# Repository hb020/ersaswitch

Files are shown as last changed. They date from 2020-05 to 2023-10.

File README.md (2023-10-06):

# ersaswitch

This project is about an external switch to an Ersa i-CON controller.
It allows switching between tools, without voiding Ersa warranty (at least, nothing from Ersa is opened and no wires are cut), and without occupying more desk space.

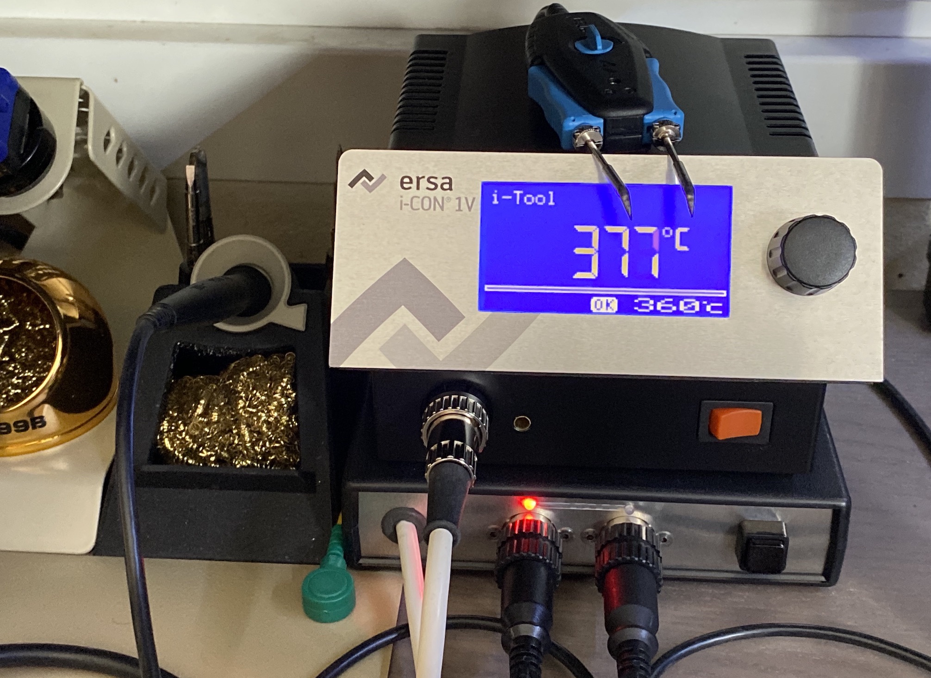
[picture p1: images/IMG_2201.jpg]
how it looks like


Inspired by https://www.eevblog.com/forum/reviews/ersa-i-con2v-(port-switch-hack)/

But I have an i-con 1V.

The switch has 3 states: left, right and a timed inbetween "no tool". The latter is mandatory between left/right tools for about 2 secs for the controller to not freak out. The switch is fully isolated, and via monitoring of the signals, switches itself on and off automatically in sync with the controller.

There is stuff inside this git repo about implementing communication with the tools to show "too hot to touch" temperatures of the disconnected tool, but that was put on hold, as I wanted to try out the Attiny 214. That guy would probably be too small for a full comms stack and it would require some more components and a lot more time.

Does the switch work well? Yes, and it is a joy too, since the heat up time of the tools is so short. Really easy to use. One big pushbutton. I designed it so that the relay click pattern gives audible hints too, so in short time you don't even have to look anymore as for what tool is active. You just grab it.

Is it economically viable? Probably not for a one-off, as the BOM gets close to 100 EUR if you have to buy it all (meaning: case and so) in small qty locally from Europe or the US. Just get the i-con 2V if you really use multiple tools regularly. But on the other hand you could use this to extend the port range of a 2V to 3 tools or more if you want (while keeping your warranty).

This should be easy to extend to 3 or more tools though. Just keep in mind that not all Ersa tools use only 5 wires. I have the i-tool and the Chip Tool Vario, and they only have 2 for power, 2 for logic, and 1 for earth. Some tools have more lines. If you have a tool with more lines, you'll have to change the relays.

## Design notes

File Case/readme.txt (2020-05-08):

PCB cutout: generated by flatcam 8.99.. beta.
frontcutouts: QCad to bCNC, tweaked manually (and moved some)

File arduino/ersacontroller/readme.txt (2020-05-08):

How to program the Attiny 214:

You need an Arduino Nano or the like, programmed as jtag2updi.

Use the Arduino IDE for dev and programming. 
It is not my preferred environment, but it was the easiest way to get started with the Attiny 214 through MegaTinyCore.

Inside Arduino IDE:

Board: ATtiny1614/...../214/...
Chip: 214
Port: /dev/cu.usbserial-10
Programmer: jtag2updi (MegaTinyCore)

Arduino IDE digitalRead/Write pin naming:
0 = PA4 (chip pin 2)
1 = PA5 (chip pin 3)
2 = PA6 (chip pin 4)
3 = PA7 (chip pin 5)
4 = PB3 (chip pin 6)
5 = PB2 (chip pin 7)
6 = PB1 (chip pin 8)
7 = PB0 (chip pin 9)
8 = PA1 (chip pin 11)
9 = PA2 (chip pin 12)
10 = PA3 (chip pin 13)

Investigate board:

> wget https://raw.githubusercontent.com/ElTangas/jtag2updi/master/avrdude.conf
> avrdude -c jtag2updi -P /dev/tty.usbserial-10 -p t214 -v -C avrdude.conf

avrdude: Version 6.3, compiled on Oct 11 2019 at 01:39:52
         Copyright (c) 2000-2005 Brian Dean, http://www.bdmicro.com/
         Copyright (c) 2007-2014 Joerg Wunsch

         System wide configuration file is "avrdude.conf"
         User configuration file is "/Users/hboot/.avrduderc"
         User configuration file does not exist or is not a regular file, skipping

         Using Port                    : /dev/tty.usbserial-10
         Using Programmer              : jtag2updi
JTAG ICE mkII sign-on message:
Communications protocol version: 1
M_MCU:
  boot-loader FW version:        1
  firmware version:              6.00
  hardware version:              1
S_MCU:
  boot-loader FW version:        1
  firmware version:              6.00
  hardware version:              1
Serial number:                   00:00:00:00:00:00
Device ID:                       JTAGICE mkII
         AVR Part                      : ATtiny214
         Chip Erase delay              : 0 us
         PAGEL                         : P00
         BS2                           : P00
         RESET disposition             : dedicated
         RETRY pulse                   : SCK
         serial program mode           : yes
         parallel program mode         : yes
         Timeout                       : 0
         StabDelay                     : 0
         CmdexeDelay                   : 0
         SyncLoops                     : 0
         ByteDelay                     : 0
         PollIndex                     : 0
         PollValue                     : 0x00
         Memory Detail                 :

                                  Block Poll               Page                       Polled
           Memory Type Mode Delay Size  Indx Paged  Size   Size #Pages MinW  MaxW   ReadBack
           ----------- ---- ----- ----- ---- ------ ------ ---- ------ ----- ----- ---------
           signature      0     0     0    0 no          3    0      0     0     0 0x00 0x00
           prodsig        0     0     0    0 no         61   61      0     0     0 0x00 0x00
           fuses          0     0     0    0 no          9    0      0     0     0 0x00 0x00
           fuse0          0     0     0    0 no          1    0      0     0     0 0x00 0x00
           fuse1          0     0     0    0 no          1    0      0     0     0 0x00 0x00
           fuse2          0     0     0    0 no          1    0      0     0     0 0x00 0x00
           fuse4          0     0     0    0 no          1    0      0     0     0 0x00 0x00
           fuse5          0     0     0    0 no          1    0      0     0     0 0x00 0x00
           fuse6          0     0     0    0 no          1    0      0     0     0 0x00 0x00
           fuse7          0     0     0    0 no          1    0      0     0     0 0x00 0x00
           fuse8          0     0     0    0 no          1    0      0     0     0 0x00 0x00
           lock           0     0     0    0 no          1    0      0     0     0 0x00 0x00
           data           0     0     0    0 no          0    0      0     0     0 0x00 0x00
           usersig        0     0     0    0 no         32   32      0     0     0 0x00 0x00
           flash          0     0     0    0 no       2048   64      0     0     0 0x00 0x00
           eeprom         0     0     0    0 no         64   32      0     0     0 0x00 0x00

         Programmer Type : JTAGMKII_PDI
         Description     : JTAGv2 to UPDI bridge
         M_MCU hardware version: 1
         M_MCU firmware version: 6.00
         S_MCU hardware version: 1
         S_MCU firmware version: 6.00
         Serial number:          00:00:00:00:00:00
         Vtarget         : 5.0 V

avrdude: AVR device initialized and ready to accept instructions

Reading | ################################################## | 100% 0.05s

avrdude: Device signature = 0x1e9120 (probably t214)

avrdude done.  Thank you.

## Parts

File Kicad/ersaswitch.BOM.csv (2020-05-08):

Ref | Value | Footprint
C1 | 100nF | Capacitor_SMD:C_1206_3216Metric_Pad1.42x1.75mm_HandSolder
C2 | 100nF | Capacitor_SMD:C_1206_3216Metric_Pad1.42x1.75mm_HandSolder
C3 | 470uF | Capacitor_THT:CP_Radial_D10.0mm_P5.00mm
C4 | 100nF | Capacitor_SMD:C_1206_3216Metric_Pad1.42x1.75mm_HandSolder
C5 | 100uF | Capacitor_THT:CP_Radial_D6.3mm_P2.50mm
C6 | 100uF | Capacitor_THT:CP_Radial_D6.3mm_P2.50mm
C7 | 100nF | Capacitor_SMD:C_1206_3216Metric_Pad1.42x1.75mm_HandSolder
C8 | 4u7F | Capacitor_THT:CP_Radial_D5.0mm_P2.00mm
C9 | 100nF | Capacitor_SMD:C_1206_3216Metric_Pad1.42x1.75mm_HandSolder
C10 | 100nF | Capacitor_SMD:C_1206_3216Metric_Pad1.42x1.75mm_HandSolder
C11 | 100nF | Capacitor_SMD:C_1206_3216Metric_Pad1.42x1.75mm_HandSolder
C12 | 100nF | Capacitor_SMD:C_1206_3216Metric_Pad1.42x1.75mm_HandSolder
D1 | 1N4001 | Diode_SMD:D_SOD-123
D2 | 1N4001 | Diode_SMD:D_SOD-123
D3 | 1N4148 | Diode_SMD:D_SOD-123
D4 | 1N4148 | Diode_SMD:D_SOD-123
D5 | LED2_Dual_CAC | LED_THT:LED_D3.0mm-3
D6 | LED1_Dual_CAC | LED_THT:LED_D3.0mm-3
H1 | MountingHole | MountingHole:MountingHole_3mm
H2 | MountingHole | MountingHole:MountingHole_3mm
H3 | MountingHole | MountingHole:MountingHole_3mm
H4 | MountingHole | MountingHole:MountingHole_3mm
H5 | MountingHole | MountingHole:MountingHole_3mm
H6 | MountingHole | MountingHole:MountingHole_3mm
H7 | MountingHole | MountingHole:MountingHole_3mm
H8 | MountingHole | MountingHole:MountingHole_3mm
J1 | Conn_01x03_Male | TerminalBlock_Phoenix:TerminalBlock_Phoenix_MKDS-1,5-3-5.08_1x03_P5.08mm_Horizontal
J2 | Conn_01x01_Female | Connector_PinSocket_2.54mm:PinSocket_1x01_P2.54mm_Vertical
J3 | Conn_01x01_Male | Connector_PinHeader_2.54mm:PinHeader_1x01_P2.54mm_Horizontal
J4 | Conn_01x02_Male | mylib:PinHeader_1x02_P2.54mm_Vertical_for_rivets
J5 | Conn_01x06_Male | mylib:PinHeader_1x06_P2.54mm_Vertical_for_rivets
J6 | Conn_01x03_Male | mylib:PinHeader_1x03_P2.54mm_Vertical_biggerpads
J7 | Barrel_Jack_Switch | Connector_BarrelJack:BarrelJack_CUI_PJ-102AH_Horizontal
J8 | Conn_01x02_Male | mylib:PinHeader_1x02_P2.54mm_Vertical_for_rivets
J9 | Conn_01x06_Male | mylib:PinHeader_1x06_P2.54mm_Vertical_for_rivets
J10 | Conn_01x03_Male | Connector_PinHeader_2.54mm:PinHeader_1x03_P2.54mm_Horizontal
J11 | Conn_01x03_Female | Connector_PinSocket_2.54mm:PinSocket_1x03_P2.54mm_Vertical
J12 | Conn_01x03_Male | TerminalBlock_Phoenix:TerminalBlock_Phoenix_MKDS-1,5-3-5.08_1x03_P5.08mm_Horizontal
J13 | Conn_01x04_Male | TerminalBlock_Phoenix:TerminalBlock_Phoenix_MKDS-1,5-4-5.08_1x04_P5.08mm_Horizontal
J14 | Conn_01x03_Male | TerminalBlock_Phoenix:TerminalBlock_Phoenix_MKDS-1,5-3_1x03_P5.00mm_Horizontal
J15 | Conn_01x03_Male | TerminalBlock_Phoenix:TerminalBlock_Phoenix_MKDS-1,5-3_1x03_P5.00mm_Horizontal
J16 | Conn_01x01_Male | Connector_PinHeader_2.54mm:PinHeader_1x01_P2.54mm_Horizontal
J17 | Conn_01x01_Male | Connector_PinHeader_2.54mm:PinHeader_1x01_P2.54mm_Horizontal
J18 | Conn_01x01_Female | Connector_PinSocket_2.54mm:PinSocket_1x01_P2.54mm_Vertical
J19 | Conn_01x01_Female | Connector_PinSocket_2.54mm:PinSocket_1x01_P2.54mm_Vertical
J20 | Conn_01x01_Female | Connector_PinSocket_2.54mm:PinSocket_1x01_P2.54mm_Vertical
J21 | Conn_01x01_Male | Connector_PinHeader_2.54mm:PinHeader_1x01_P2.54mm_Horizontal
J22 | Conn_01x01_Female | Connector_PinSocket_2.54mm:PinSocket_1x01_P2.54mm_Vertical
J23 | Conn_01x01_Male | Connector_PinHeader_2.54mm:PinHeader_1x01_P2.54mm_Horizontal
J24 | Conn_01x01_Female | Connector_PinSocket_2.54mm:PinSocket_1x01_P2.54mm_Vertical
J25 | Conn_01x01_Male | Connector_PinHeader_2.54mm:PinHeader_1x01_P2.54mm_Horizontal
K1 | FINDER-41.52 | Relay_THT:Relay_DPDT_Finder_40.52
K2 | FINDER-41.52 | Relay_THT:Relay_DPDT_Finder_40.52
L1 | 18uH | Inductor_SMD:L_Taiyo-Yuden_NR-50xx_HandSoldering
PS1 | B1205LS-1WR2 | mylib:Converter_DCDC_BxxxxLS-1WR2
Q1 | BC817 | Package_TO_SOT_SMD:SOT-23
Q2 | BC817 | Package_TO_SOT_SMD:SOT-23
Q3 | IRFR5305 | Package_TO_SOT_SMD:TO-252-2
R1 | 4k7 | Resistor_SMD:R_1206_3216Metric_Pad1.42x1.75mm_HandSolder
R2 | 4k7 | Resistor_SMD:R_1206_3216Metric_Pad1.42x1.75mm_HandSolder
R3 | 1k? | Resistor_SMD:R_1206_3216Metric_Pad1.42x1.75mm_HandSolder
R4 | 10k | Resistor_SMD:R_1206_3216Metric_Pad1.42x1.75mm_HandSolder
R5 | 1M | Resistor_SMD:R_1206_3216Metric_Pad1.42x1.75mm_HandSolder
R6 | 4k7 | Resistor_SMD:R_1206_3216Metric_Pad1.42x1.75mm_HandSolder
R7 | 1k | Resistor_SMD:R_1206_3216Metric_Pad1.42x1.75mm_HandSolder
R8 | 10k | Resistor_SMD:R_1206_3216Metric_Pad1.42x1.75mm_HandSolder
R9 | 4k7 | Resistor_SMD:R_1206_3216Metric_Pad1.42x1.75mm_HandSolder
R10 | 680 | Resistor_SMD:R_1206_3216Metric_Pad1.42x1.75mm_HandSolder
R11 | 470 | Resistor_SMD:R_1206_3216Metric_Pad1.42x1.75mm_HandSolder
R12 | 680 | Resistor_SMD:R_1206_3216Metric_Pad1.42x1.75mm_HandSolder
R13 | 470 | Resistor_SMD:R_1206_3216Metric_Pad1.42x1.75mm_HandSolder
R14 | 0R | Resistor_SMD:R_2010_5025Metric_Pad1.52x2.65mm_HandSolder
R15 | 0R | Resistor_SMD:R_2010_5025Metric_Pad1.52x2.65mm_HandSolder
R16 | 0R | Resistor_SMD:R_2010_5025Metric_Pad1.52x2.65mm_HandSolder
R17 | 0R | Resistor_SMD:R_2010_5025Metric_Pad1.52x2.65mm_HandSolder
SW1 | SW_Push (connection) | mylib:PinHeader_1x02_P2.54mm_Vertical_for_rivets
U1 | ATtiny214-SS | Package_SO:SOIC-14_3.9x8.7mm_P1.27mm
U2 | AMS1117-5.0 | Package_TO_SOT_SMD:SOT-223-3_TabPin2
U3 | 74VHC1G132 | Package_TO_SOT_SMD:SOT-23-5_HandSoldering
U4 | PC817 | Package_DIP:DIP-4_W7.62mm_LongPads
Ref | Value | qty
Case | Hammond 1598BBBK | 1
DIN plug | PREHKEYTEC 71430-080/0800 | 1
DIN socket | PREHKEYTEC 71206-080/0800 | 2
Support for relay | Finder 95.15.2SMA | 2
PCB feet | TR FASTENINGS TRLCBSBM-4-01A2-RT - PCB Support, Lock-In Support With Adhesive Base, Nylon 6.6, 6.4mm x 4.4mm | 2
PCB feet | TR FASTENINGS TRLCBSBM-3-01A2-RT - PCB Support, Lock-In Support With Adhesive Base, Nylon 6.6, 4.8mm x 4.4mm | 2
Pushbutton | Multicomp MCPS23B-2 - Pushbutton Switch, Standard, 12 mm, SPST, (On)-Off, Square Raised | 1
fasteners |  | various
cabling |  | various

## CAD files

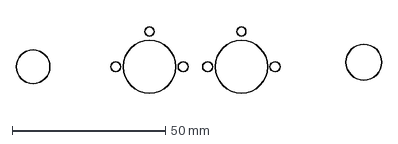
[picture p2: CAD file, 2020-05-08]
Case/frontcutouts.dxf
119.3 x 21.6 mm

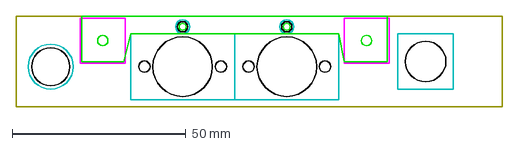
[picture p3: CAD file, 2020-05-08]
Case/front.dxf
140.0 x 26.0 mm

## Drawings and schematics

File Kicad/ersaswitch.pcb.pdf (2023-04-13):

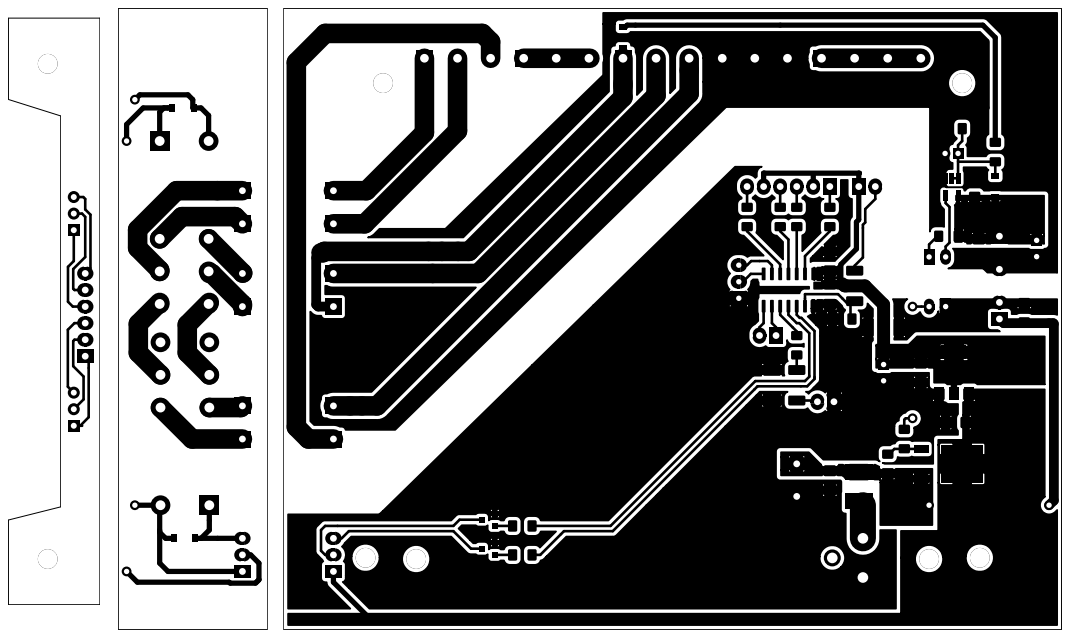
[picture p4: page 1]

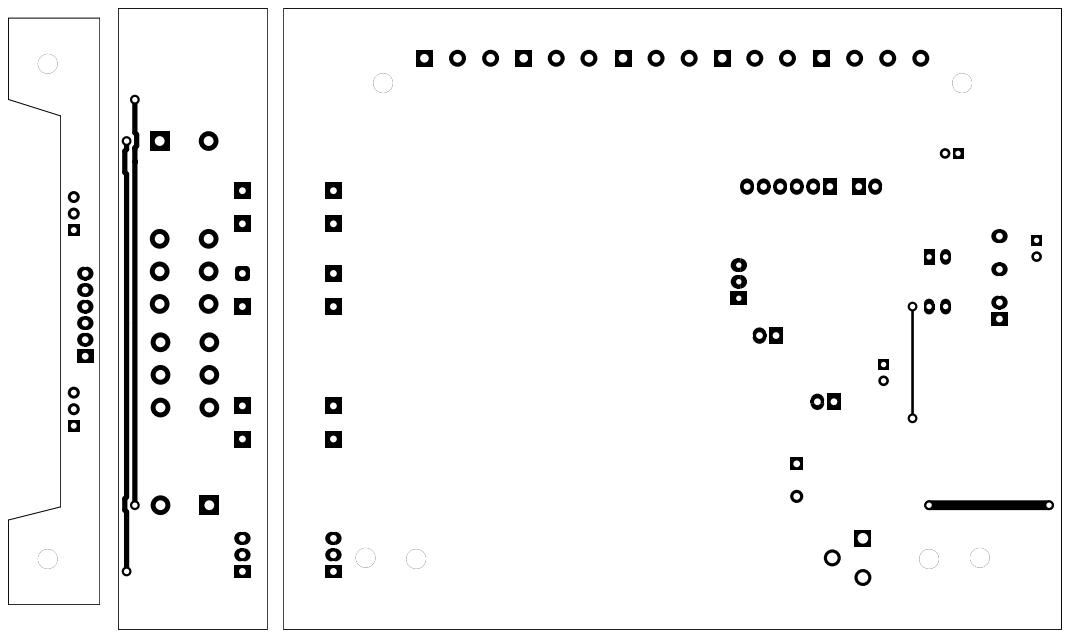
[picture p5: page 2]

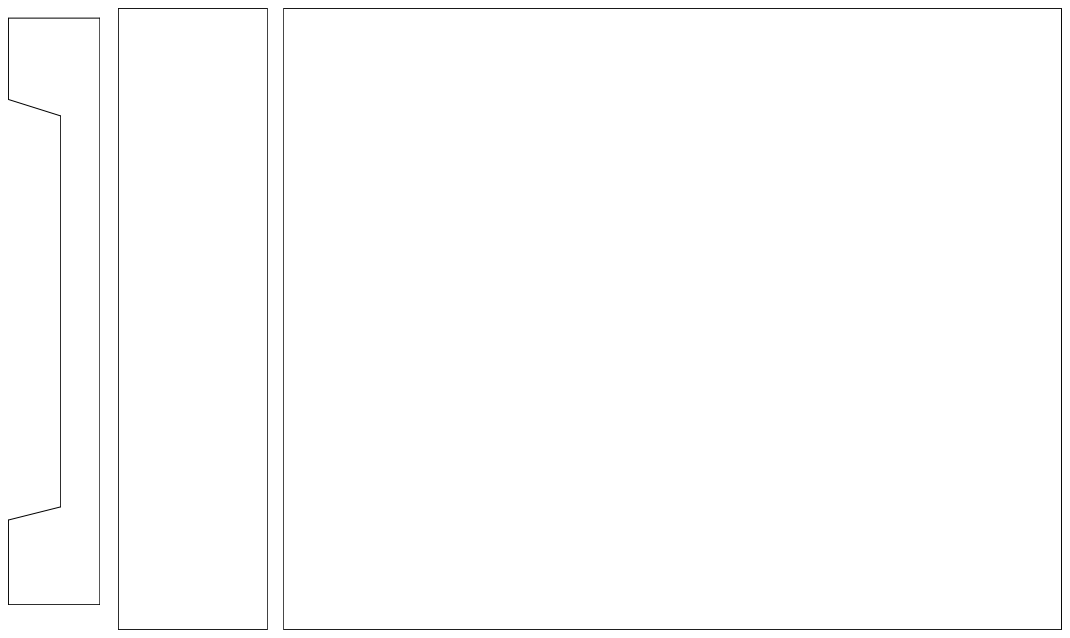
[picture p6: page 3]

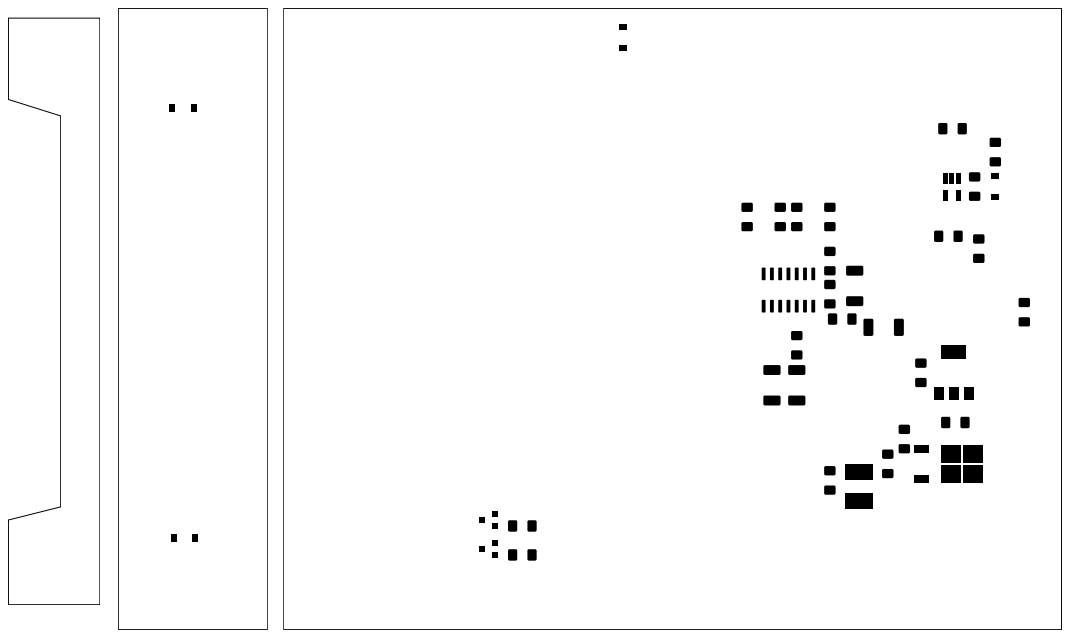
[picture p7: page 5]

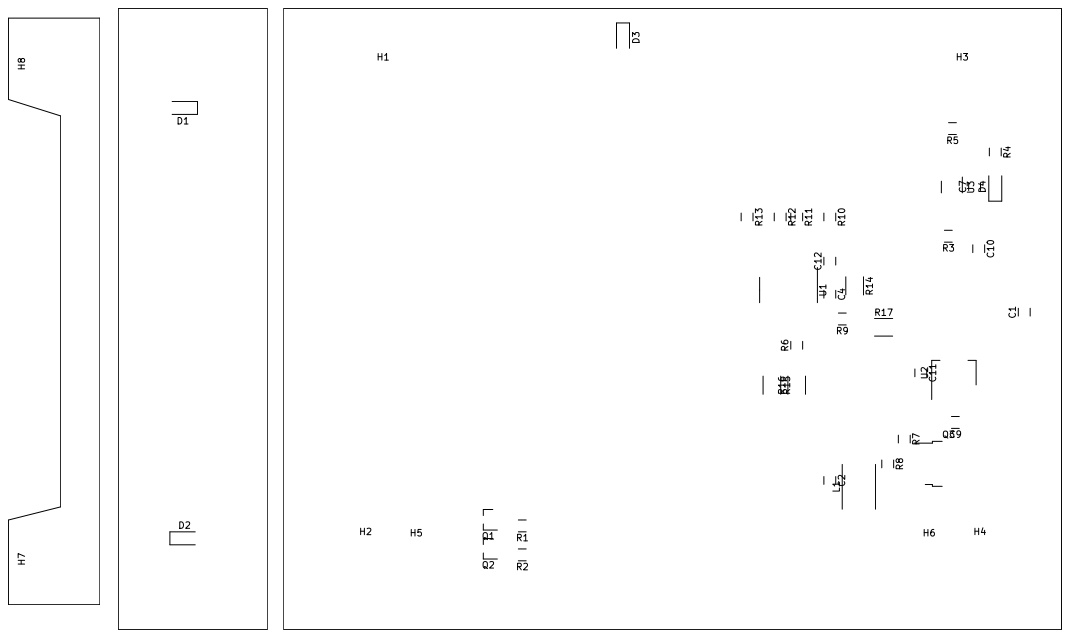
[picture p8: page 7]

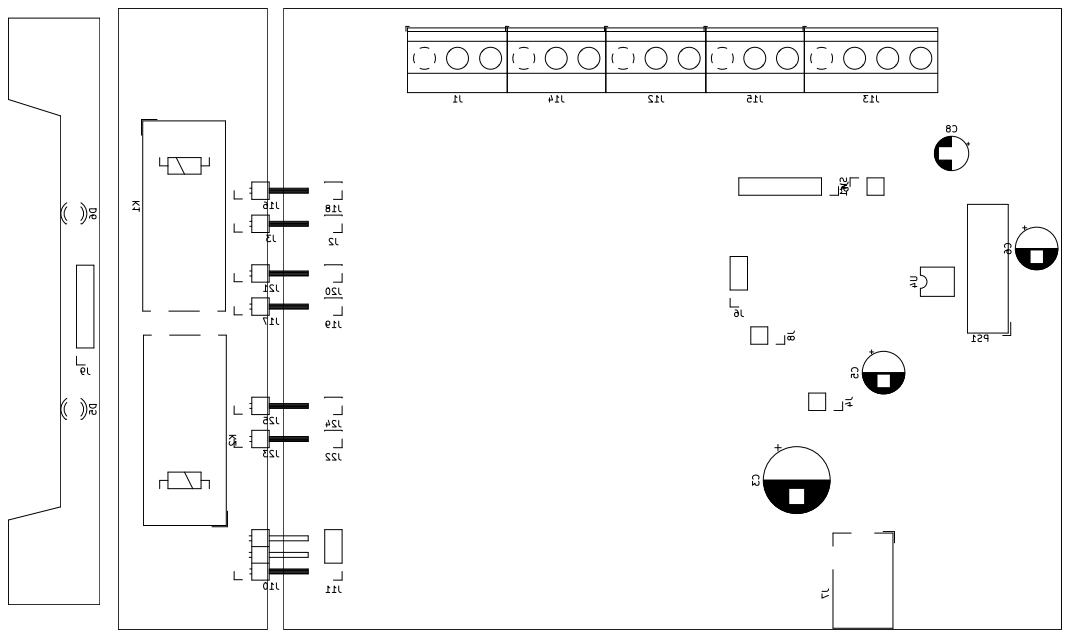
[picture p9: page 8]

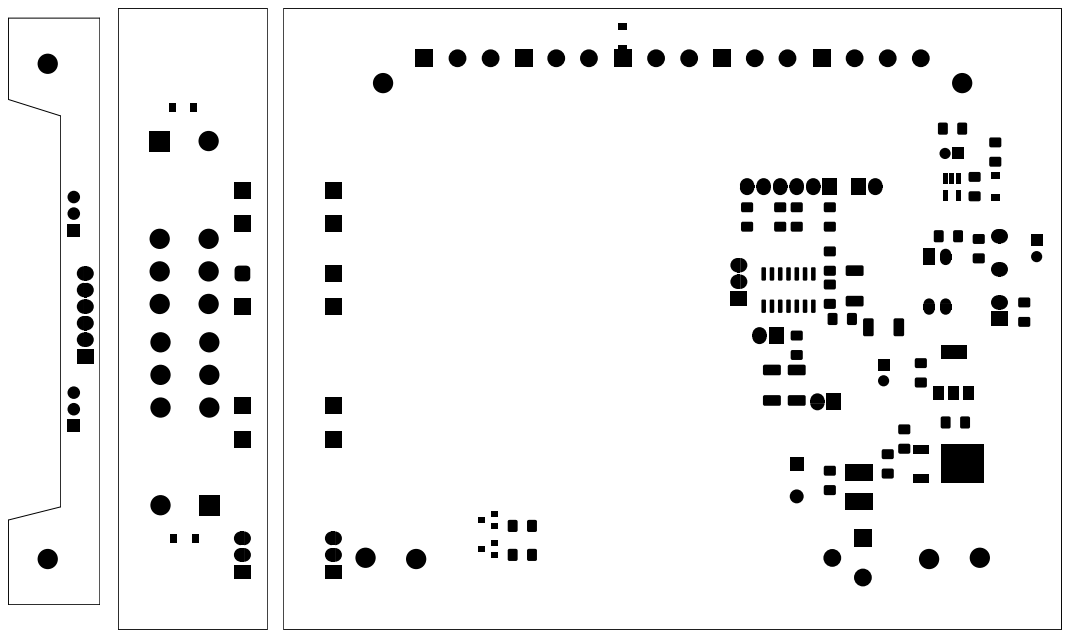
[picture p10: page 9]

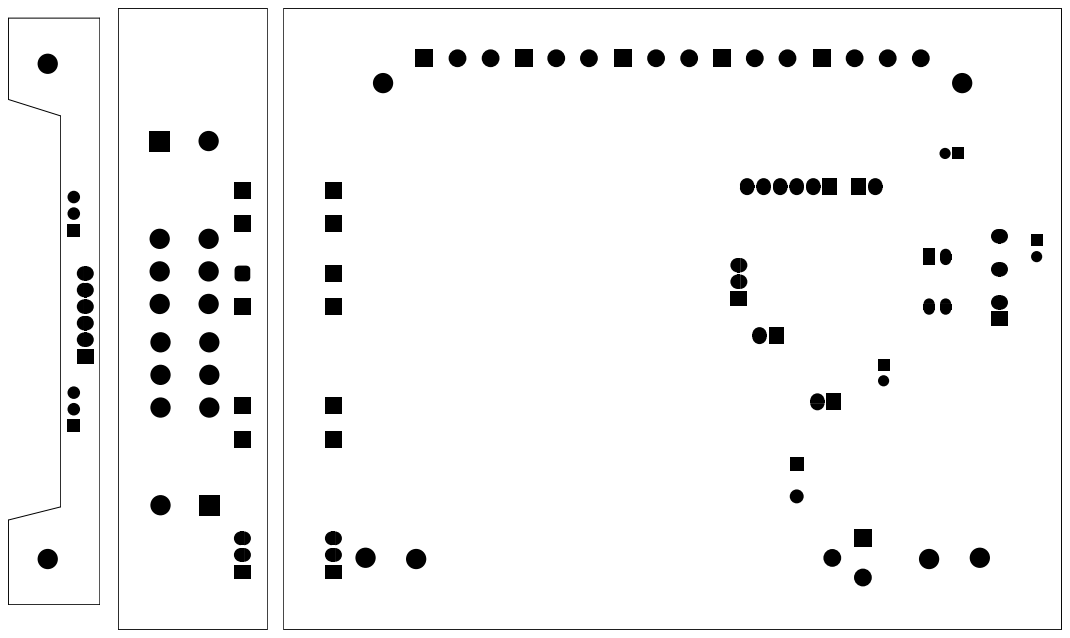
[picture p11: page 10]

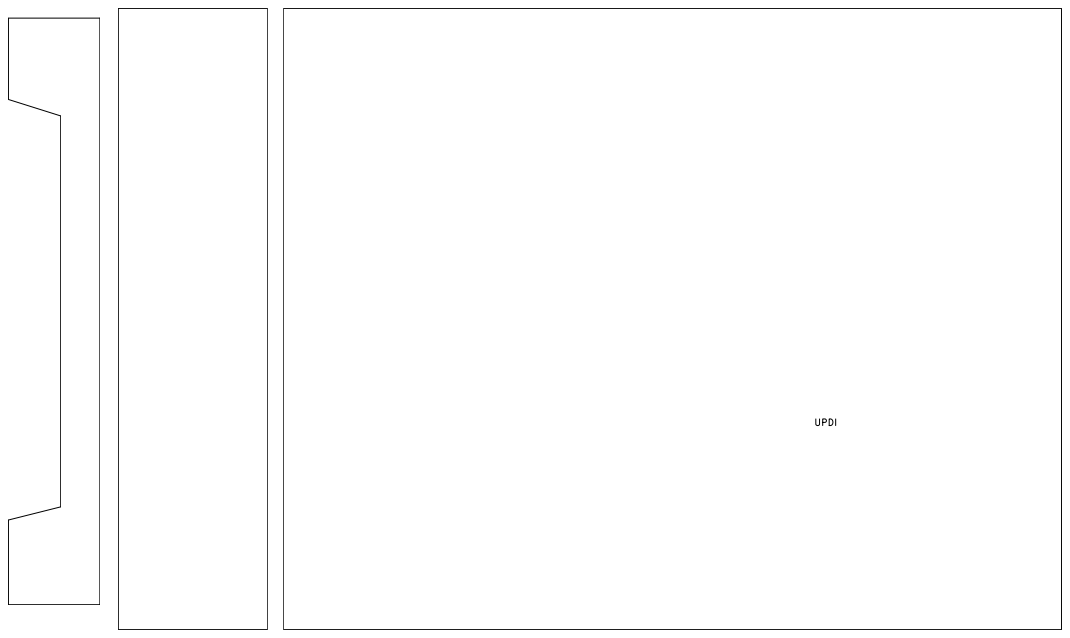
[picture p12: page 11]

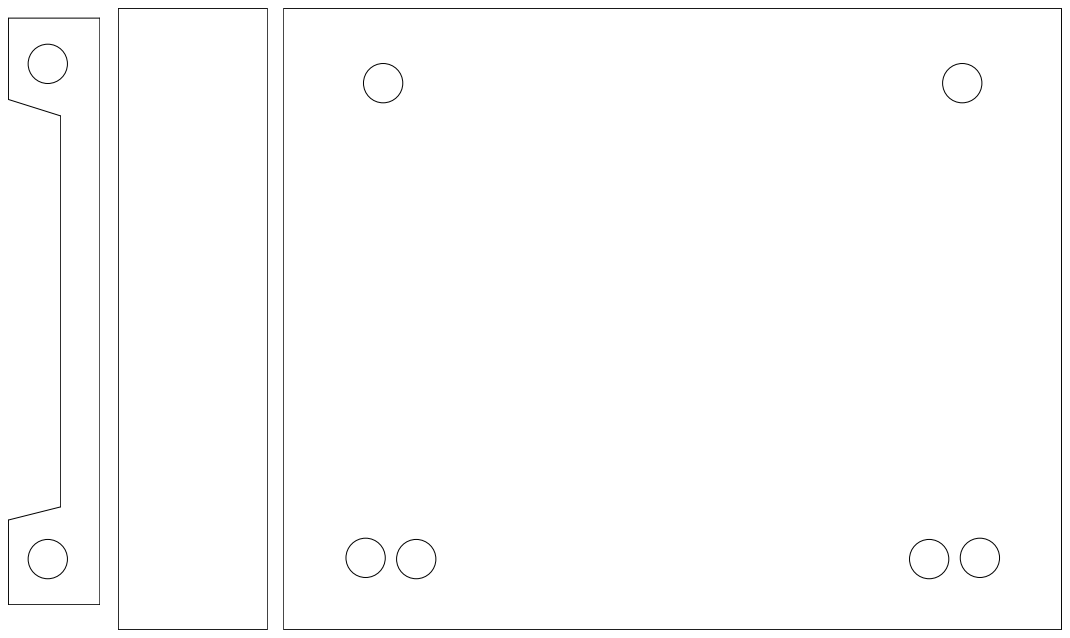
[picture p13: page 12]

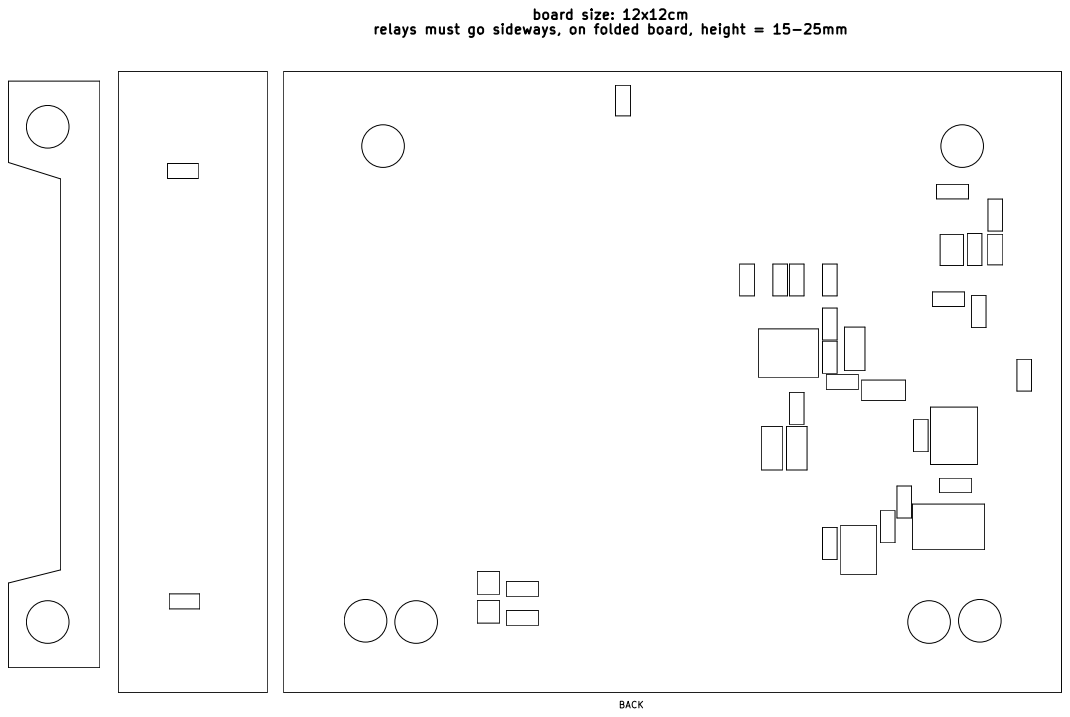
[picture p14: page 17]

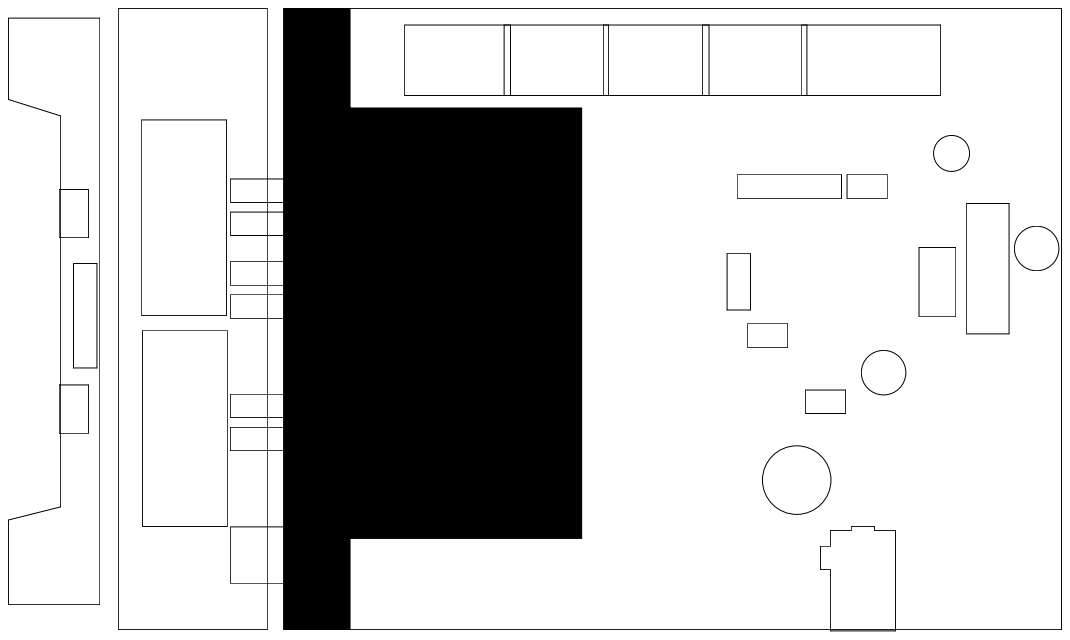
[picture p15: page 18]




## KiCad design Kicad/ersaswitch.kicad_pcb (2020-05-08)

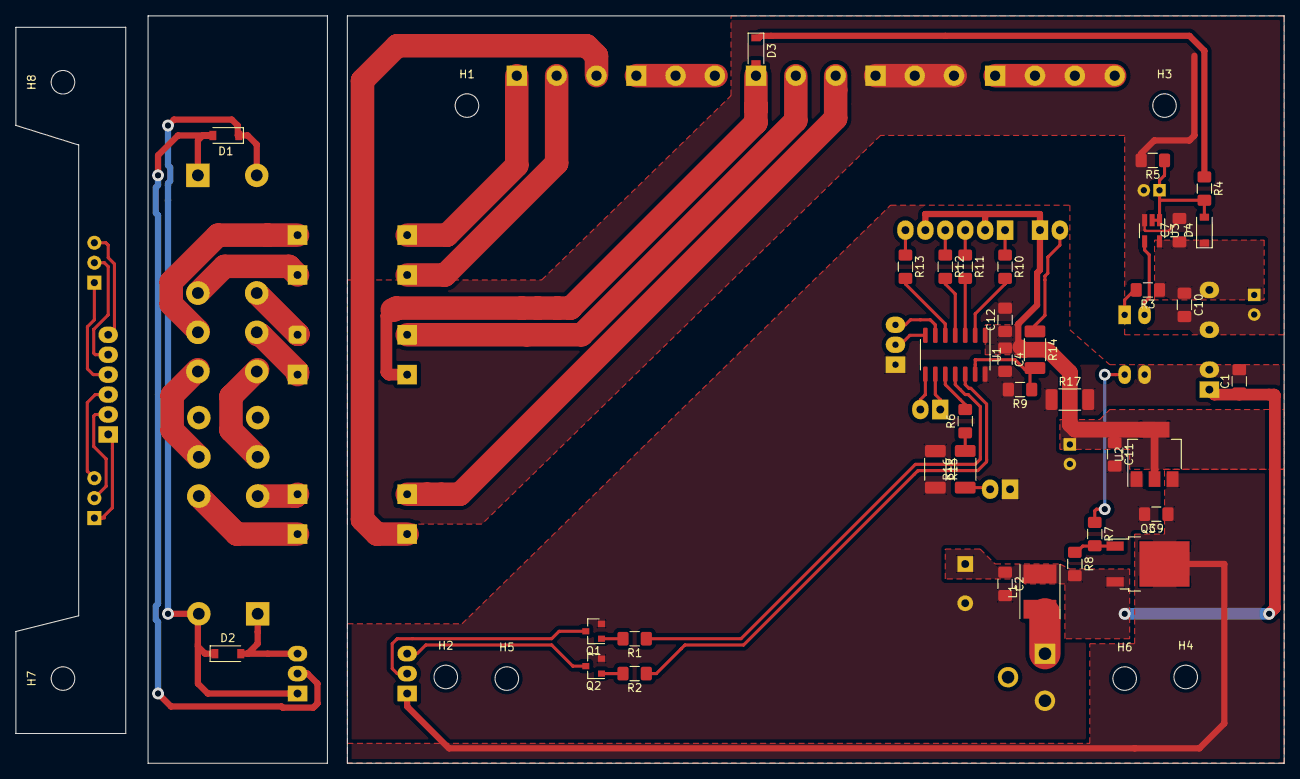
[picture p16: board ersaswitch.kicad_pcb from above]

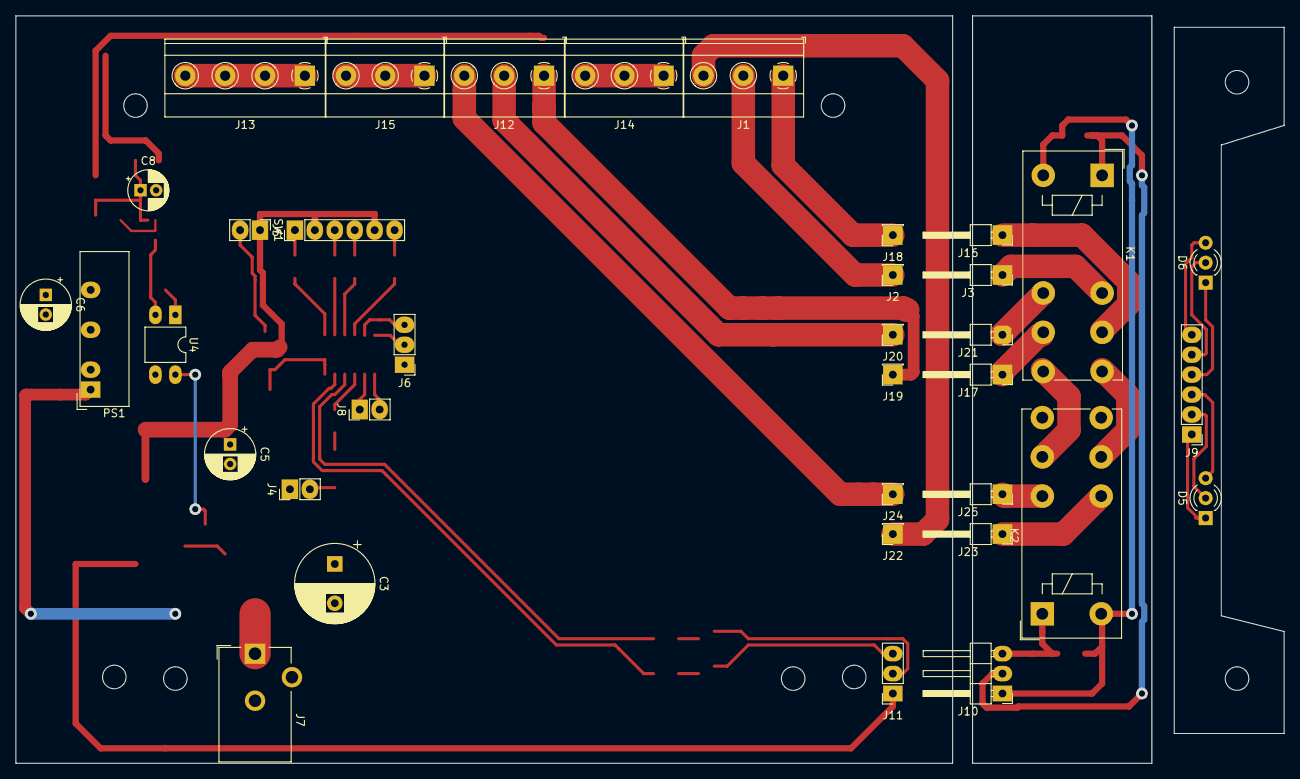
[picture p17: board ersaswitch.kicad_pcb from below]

Board: 2 copper layers, 161.6 x 95.2 mm, 80 parts (36 on the bottom side), 61 nets.

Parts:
C1, C2, C4, C7, C9, C10, C11, C12: 100nF; C_1206_3216Metric_Pad1.42x1.75mm_HandSolder
C3: 470uF; CP_Radial_D10.0mm_P5.00mm
C5, C6: 100uF; CP_Radial_D6.3mm_P2.50mm
C8: 4u7F; CP_Radial_D5.0mm_P2.00mm
D1, D2: 1N4001; D_SOD-123
D3, D4: 1N4148; D_SOD-123
D5: LED2_Dual_CAC; LED_D3.0mm-3
D6: LED1_Dual_CAC; LED_D3.0mm-3
H1, H2, H3, H4, H5, H6, H7, H8: MountingHole; MountingHole_3mm
J1, J12: Conn_01x03_Male; TerminalBlock_Phoenix_MKDS-1,5-3-5.08_1x03_P5.08mm_Horizont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
J2, J18, J19, J20, J22, J24: Conn_01x01_Female; PinSocket_1x01_P2.54mm_Vertical
J3, J16, J17, J21, J23, J25: Conn_01x01_Male; PinHeader_1x01_P2.54mm_Horizontal
J4, J8: Conn_01x02_Male; PinHeader_1x02_P2.54mm_Vertical_for_rivets
J5, J9: Conn_01x06_Male; PinHeader_1x06_P2.54mm_Vertical_for_rivets
J6: Conn_01x03_Male; PinHeader_1x03_P2.54mm_Vertical_biggerpads
J7: Barrel_Jack_Switch; BarrelJack_CUI_PJ-102AH_Horizontal
J10: Conn_01x03_Male; PinHeader_1x03_P2.54mm_Horizontal
J11: Conn_01x03_Female; PinSocket_1x03_P2.54mm_Vertical
J13: Conn_01x04_Male; TerminalBlock_Phoenix_MKDS-1,5-4-5.08_1x04_P5.08mm_Horizont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
J14, J15: Conn_01x03_Male; TerminalBlock_Phoenix_MKDS-1,5-3_1x03_P5.00mm_Horizontal
K1, K2: FINDER-41.52; Relay_DPDT_Finder_40.52
L1: 18uH; L_Taiyo-Yuden_NR-50xx_HandSoldering
PS1: B1205LS-1WR2; Converter_DCDC_BxxxxLS-1WR2
Q1, Q2: BC817; SOT-23
Q3: IRFR5305; TO-252-2
R1, R2, R6, R9: 4k7; R_1206_3216Metric_Pad1.42x1.75mm_HandSolder
R3: 1k?; R_1206_3216Metric_Pad1.42x1.75mm_HandSolder
R4, R8: 10k; R_1206_3216Metric_Pad1.42x1.75mm_HandSolder
R5: 1M; R_1206_3216Metric_Pad1.42x1.75mm_HandSolder
R7: 1k; R_1206_3216Metric_Pad1.42x1.75mm_HandSolder
R10, R12: 680; R_1206_3216Metric_Pad1.42x1.75mm_HandSolder
R11, R13: 470; R_1206_3216Metric_Pad1.42x1.75mm_HandSolder
R14, R15, R16, R17: 0R; R_2010_5025Metric_Pad1.52x2.65mm_HandSolder
SW1: SW_Push; PinHeader_1x02_P2.54mm_Vertical_for_rivets
U1: ATtiny214-SS; SOIC-14_3.9x8.7mm_P1.27mm
U2: AMS1117-5.0; SOT-223-3_TabPin2
U3: 74VHC1G132; SOT-23-5_HandSoldering
U4: PC817; DIP-4_W7.62mm_LongPads

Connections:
+5V: C4.1, C5.1, C11.1, C12.1, J5.2, J5.5, SW1.1, U1.1, U2.2
+5VA: C6.1, C7.1, C10.1, D4.1, PS1.6, R3.1, U3.5
+12C: C9.1, J11.1, Q3.2, U2.3
+12V: C1.1, C2.1, C3.1, L1.2, PS1.1, Q3.3, R8.2
/BTN: R9.1, R14.2, U1.13
/B_12V: D1.1, D2.1, J10.1, K1.A2, K2.A2
/B_HE+_1: J3.1, K1.12
/B_HE+_2: J23.1, K2.22
/B_HE+_IN: J16.1, K1.11
/B_PIO_1: J21.1, K1.22
/B_PIO_2: J25.1, K2.12
/B_PIO_IN: J17.1, K1.21
/B_Rel1: D1.2, J10.2, K1.A1
/B_Rel2: D2.2, J10.3, K2.A1
/HE+_1: J1.2, J2.1
/HE+_2: J1.3, J22.1
/HE+_IN: J1.1, J18.1
/LED1_G: J5.6, R13.1
/LED1_R: J5.4, R12.1
/LED2_G: J5.3, R11.1
/LED2_R: J5.1, R10.1
/PIO_1: J12.2, J20.1
/PIO_2: J12.3, J24.1
/PIO_IN: D3.2, J12.1, J19.1
/Rel1: R1.1, U1.11
/Rel2: R2.1, U1.12
/RxD: J6.3, U1.6
/T_Rel1: J11.2, Q1.3
/T_Rel2: J11.3, Q2.3
/TxD: J6.2, U1.7
GND: C1.2, C2.2, C3.2, C4.2, C5.2, C9.2, C11.2, C12.2, J4.1, J6.1, J7.2, PS1.2, Q1.2, Q2.2, R9.2, R15.1, R15.2, R17.1, R17.2, U1.14, U2.1, U4.3
GNDA: C6.2, C7.2, C8.2, C10.2, J15.1, J15.2, J15.3, PS1.4, R5.2, U3.3
unnamed: C8.1, D4.2, R4.2, R5.1, U3.1, U3.2
unnamed: D3.1, R4.1
unnamed: D5.1, J9.1
unnamed: D5.2, J9.2
unnamed: D5.3, J9.3
unnamed: D6.1, J9.4
unnamed: D6.2, J9.5
unnamed: D6.3, J9.6
unnamed: J4.2, R16.1
unnamed: J7.1, L1.1
unnamed: J8.1, U1.9
unnamed: J8.2, U1.8
unnamed: J13.1, J13.2, J13.3, J13.4
unnamed: J14.1, J14.2, J14.3
unnamed: K1.14, K2.21
unnamed: K1.24, K2.11
unnamed: Q1.1, R1.2
unnamed: Q2.1, R2.2
unnamed: Q3.1, R7.2, R8.1
unnamed: R3.2, U4.1
unnamed: R6.2, U1.10
unnamed: R7.1, U4.4
unnamed: R10.2, U1.2
unnamed: R11.2, U1.3
unnamed: R12.2, U1.4
unnamed: R13.2, U1.5
unnamed: R14.1, SW1.2
unnamed: R6.1, R16.2
unnamed: U3.4, U4.2

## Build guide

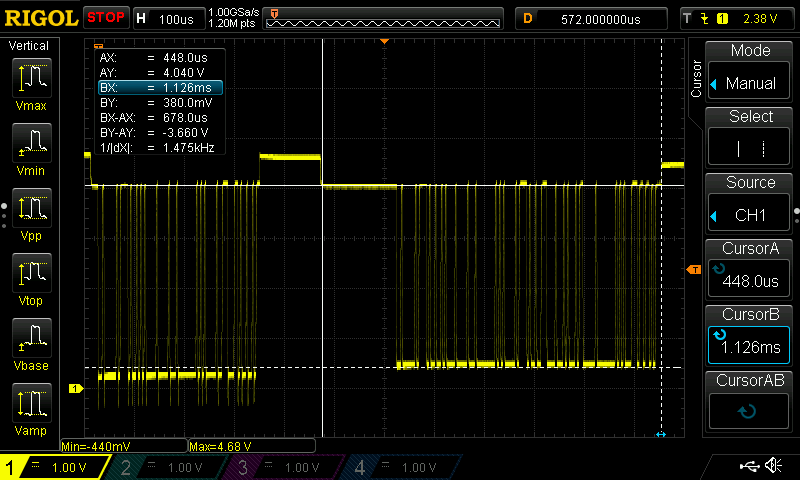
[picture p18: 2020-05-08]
Other/DS1Z_QuickPrint3.png

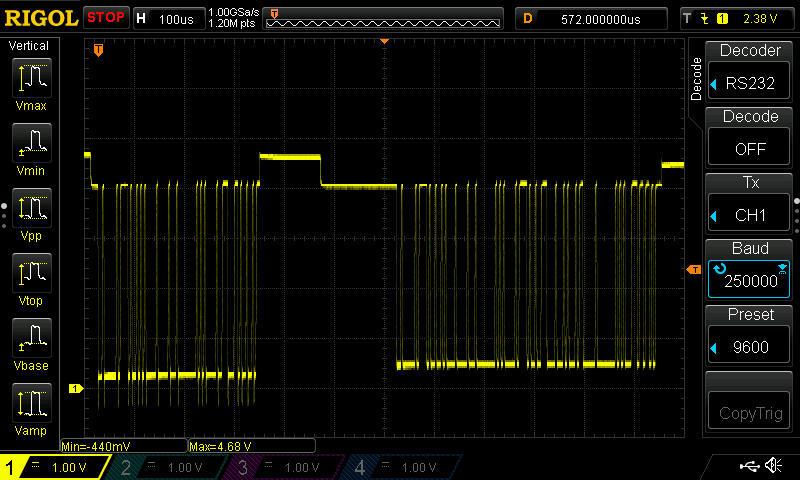
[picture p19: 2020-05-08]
Other/DS1Z_QuickPrint2.png

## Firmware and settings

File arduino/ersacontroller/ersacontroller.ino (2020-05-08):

/* #define TEST */


#ifndef TEST

//arduino digitalRead/Write pins:
//0 = PA4 (chip pin 2)
//1 = PA5 (chip pin 3)
//2 = PA6 (chip pin 4)
//3 = PA7 (chip pin 5)
//4 = PB3 (chip pin 6)
//5 = PB2 (chip pin 7)
//6 = PB1 (chip pin 8)
//7 = PB0 (chip pin 9)
//8 = PA1 (chip pin 11)
//9 = PA2 (chip pin 12)
//10 = PA3 (chip pin 13)

#define REL1 8
#define REL2 9
#define LED_1_R 2
#define LED_1_G 3
#define LED_2_R 0
#define LED_2_G 1
#define SWITCH 10

enum mystates {
  out1 = 0,
  goingto2_1,
  goingto2_2,
  out2,
  goingto1_1,
  goingto1_2
};

void setState(int state) {
  switch(state) {
    case out1:
      digitalWrite(REL1, LOW);
      digitalWrite(REL2, LOW);

      digitalWrite(LED_1_R, LOW);
      digitalWrite(LED_2_R, HIGH);
      digitalWrite(LED_1_G, HIGH);
      digitalWrite(LED_2_G, HIGH);
      break;      
    case goingto2_1:
      digitalWrite(REL1, LOW);
      digitalWrite(REL2, HIGH);

      digitalWrite(LED_1_R, LOW);
      digitalWrite(LED_2_R, HIGH);
      digitalWrite(LED_1_G, LOW);
      digitalWrite(LED_2_G, LOW);
      break;
    case goingto2_2:
      digitalWrite(REL1, HIGH);
      digitalWrite(REL2, HIGH);

      digitalWrite(LED_1_R, HIGH);
      digitalWrite(LED_2_R, LOW);
      digitalWrite(LED_1_G, LOW);
      digitalWrite(LED_2_G, LOW);
      break;
    case out2:
      digitalWrite(REL1, HIGH);
      digitalWrite(REL2, LOW);

      digitalWrite(LED_1_R, HIGH);
      digitalWrite(LED_2_R, LOW);
      digitalWrite(LED_1_G, HIGH);
      digitalWrite(LED_2_G, HIGH);
      break;
    case goingto1_1:
      digitalWrite(REL1, HIGH);
      digitalWrite(REL2, HIGH);

      digitalWrite(LED_1_R, HIGH);
      digitalWrite(LED_2_R, LOW);
      digitalWrite(LED_1_G, LOW);
      digitalWrite(LED_2_G, LOW);
      break;
    case goingto1_2:
      digitalWrite(REL1, LOW);
      digitalWrite(REL2, HIGH);

      digitalWrite(LED_1_R, LOW);
      digitalWrite(LED_2_R, HIGH);
      digitalWrite(LED_1_G, LOW);
      digitalWrite(LED_2_G, LOW);
      break;
  }
}

// The minimum time relays take to switch over. I am not allowed to switch the 2 at the same time.
#define RELAY_MIN_SWITCH_TIME_MSECS 100L

// The minimum time the ersa controller must see no tool connected to detect "No Tool" (the above will be added)
#define TOOL_SWITCH_TIME_MSECS 2000L

unsigned long getStateMaxTime_msec(int state) {
  switch(state) {
    case out1:
      return 0;  
    case goingto2_1:
      return RELAY_MIN_SWITCH_TIME_MSECS;
    case goingto2_2:
      return TOOL_SWITCH_TIME_MSECS;
    case out2:
      return 0;
    case goingto1_1:
      return TOOL_SWITCH_TIME_MSECS;
    case goingto1_2:
      return RELAY_MIN_SWITCH_TIME_MSECS;
  }
}

int mystate = out1;
unsigned long lastStateStartTime = 0;  // the last time state changed

void stateMaintenance() {
  unsigned long shouldWait = 0;
  bool shouldMoveOn = false;

  shouldWait = getStateMaxTime_msec(mystate);
  if (shouldWait == 0) {
    shouldMoveOn = switchGotPushed();
  }
  else {
    if ((millis() - lastStateStartTime) > shouldWait) {
      shouldMoveOn = true;
    }
  }

  if (shouldMoveOn) {
    lastStateStartTime = millis();
    mystate += 1;
    if (mystate > goingto1_2) {
      mystate = out1;
    }
  }
  setState(mystate);
}


// Variables will change:
int debouncedButtonState = LOW;  // the debounced reading from the input pin
int lastButtonState = LOW;   // the previous reading from the input pin

// the following variables are unsigned longs because the time, measured in
// milliseconds, will quickly become a bigger number than can be stored in an int.
unsigned long lastDebounceTime = 0;  // the last time the input pin was toggled
#define debounceDelay 50L    // the debounce time; increase if the output flickers


bool switchGotPushed() {
  bool justGotPushed = false;
  // read the state of the switch into a local variable:
  int reading = digitalRead(SWITCH);

  // check to see if you just pressed the button
  // (i.e. the input went from LOW to HIGH), and you've waited long enough
  // since the last press to ignore any noise:

  // If the switch changed, due to noise or pressing:
  if (reading != lastButtonState) {
    // reset the debouncing timer
    lastDebounceTime = millis();
  }

  // save the reading. Next time through the loop, it'll be the lastButtonState:
  lastButtonState = reading;
  
  if ((millis() - lastDebounceTime) > debounceDelay) {
    // whatever the reading is at, it's been there for longer than the debounce
    // delay, so take it as the actual current state:

    // if the button state has changed:
    if (reading != debouncedButtonState) {
      debouncedButtonState = reading;

      if (debouncedButtonState == HIGH) {
        justGotPushed = true;
      }
    }
  }

  return justGotPushed;
}

void setup() {
  
  digitalWrite(REL1, LOW);
  pinMode(REL1,OUTPUT);
  digitalWrite(REL1, LOW);
  
  digitalWrite(REL2, LOW);
  pinMode(REL2,OUTPUT);
  digitalWrite(REL2, LOW);

  digitalWrite(LED_1_R, HIGH);
  pinMode(LED_1_R,OUTPUT);
  digitalWrite(LED_1_R, HIGH);

  digitalWrite(LED_1_G, HIGH);
  pinMode(LED_1_G,OUTPUT);
  digitalWrite(LED_1_G, HIGH);

  digitalWrite(LED_2_R, HIGH);
  pinMode(LED_2_R,OUTPUT);
  digitalWrite(LED_2_R, HIGH);

  digitalWrite(LED_2_G, HIGH);
  pinMode(LED_2_G,OUTPUT);
  digitalWrite(LED_2_G, HIGH);

  pinMode(SWITCH,INPUT);
  
}

void loop() {

  stateMaintenance();
  
}


#else

#define MYPIN 1

int loopnr;

int offset = 0;
int maxnr = 11;

void setup() {
  for (int i = 0; i < maxnr; i++) {
    pinMode(i+offset,OUTPUT);
    digitalWrite(i+offset, HIGH);
  }
  loopnr = 0;
}


void loop() {
  loopnr += 1;
  for (int i = 0; i < maxnr; i++) {
    if (loopnr % (i+1) == 0) {
      int x = loopnr / (i+1);
      if (x & 1) {
        digitalWrite(i+offset, HIGH);
      } else {
        digitalWrite(i+offset, LOW);        
      }
    }
  }
  delay(100);
}

#endif
